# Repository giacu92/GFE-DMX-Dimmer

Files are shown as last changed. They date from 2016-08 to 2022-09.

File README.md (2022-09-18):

# DMX-Dimmer
DIY 5 channels dmx dimmer for 4 stage halogen lights.

Get the full assembled board: [http://gfehandmade.bigcartel.com/product/dmx-dimmer-for-4-stage-halogen-lamps](http://giacu92.bigcartel.com/product/dmx-dimmer-for-4-stage-halogen-lamps)

* Author: Giacomo Mammarella
* email: giacu92@gmail.com
* [YouTube video test 1](https://www.youtube.com/watch?v=KfEGCJoeCmY): testing video n1: lamp test
* [YouTube video test 2](https://www.youtube.com/watch?v=TXi1G5LvkLE): testing video n2: strobe and dimming

# About software:
The software is based on a finite state machine. The DMX start address can be choosen on the software  modifying "#define DMX_START_ADDRESS 65".
The DMX channels are currently set like following:
* DMX CHANNEL 65: lamp 1 dimmer (0 -> 100% fade)
* DMX CHANNEL 66: lamp 2 dimmer 
* DMX CHANNEL 67: lamp 3 dimmer 
* DMX CHANNEL 68: lamp 4 dimmer 
* DMX CHANNEL 69: strobo all lamps at chosen speed (40 - 255 strobe from 100ms to 1s)

# _HardwareSerial0.cpp EDIT:_
To let Arduino IDE compile the code we need to do some mods to the _HardwareSerial0.cpp_ file.
On my current Mac OSX Arduino version (1.6.10) the file is placed at the following path:
**Arduino/Contents/Java/hardware/arduino/avr/cores/arduino/HardwareSerial0.cpp**.
Inside it we need to comment out the whole block between line 40 and line 51:
```
/*
#if defined(USART_RX_vect)
  ISR(USART_RX_vect)
#elif defined(USART0_RX_vect)
  ISR(USART0_RX_vect)
#elif defined(USART_RXC_vect)
  ISR(USART_RXC_vect) // ATmega8
#else
  #error "Don't know what the Data Received vector is called for Serial"
#endif
  {
    Serial._rx_complete_irq();
  }
*/
```
That's because we need to tell the Arduino IDE that inside the code we wrote our personal Interrupt Service Routine ("ISR") and we need it to use it in DMX serial communications.
Remember to remove the mods after uploading the code or Serial communications ( like the one we use in Serial.print() ) wont work anymore.

You can find my copy of modded _HardwareSerial0.cpp_ inside the file list.

# File list:
* [DMX_dimmer.brd](https://github.com/giacu92/DMX-Dimmer/blob/master/DMX_dimmer.brd): the Cadsoft Eagle 6.5 board file.
* [DMX_dimmer.sch](https://github.com/giacu92/DMX-Dimmer/blob/master/DMX_dimmer.sch): the Cadsoft Eagle 6.5 schematic file for the board.
* [Code](https://github.com/giacu92/DMX-Dimmer/tree/master/dmx_dimmer): the folder containingh the sketch for the project.
* [HardwareSerial0.cpp](https://github.com/giacu92/DMX-Dimmer/blob/master/HardwareSerial0.cpp): The **MODIFIED** _HardwareSerial0.cpp_ for uploading the code

# Connections:
Board

# Some pics:
Painting the enclosure and test fitting the pcb:


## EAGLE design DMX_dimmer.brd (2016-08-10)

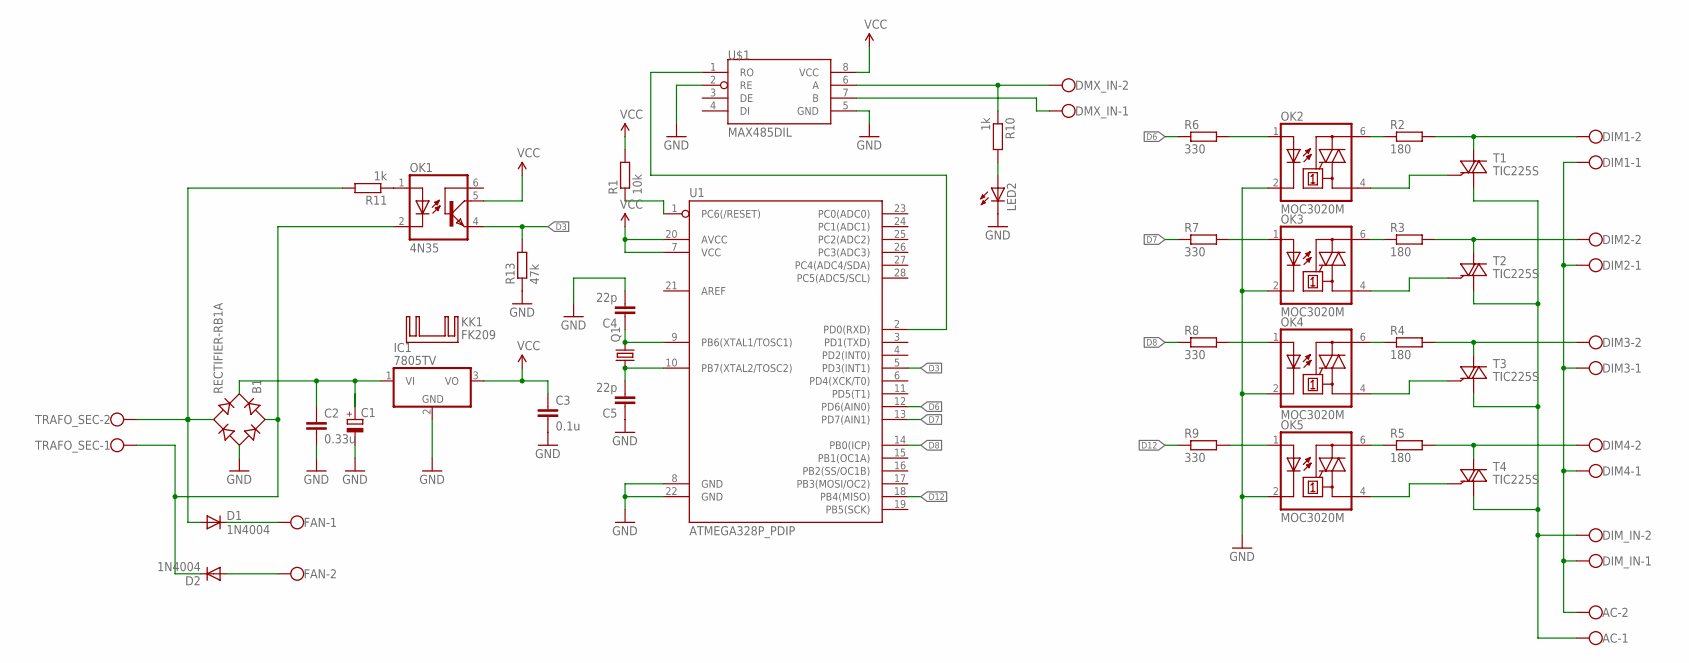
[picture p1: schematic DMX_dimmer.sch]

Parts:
AC: W237-102
B1: RECTIFIER-RB1A; RB1A
C1: CPOL-EUE5-10.5; E5-10,5
C2: 0.33u; C050-024X044
C3: 0.1u; C050-024X044
C4, C5: 22p; C025-024X044
D1, D2: 1N4004; DO41-10
DIM1, DIM2, DIM3, DIM4: W237-102
DIM_IN: W237-102
DMX_IN: W237-102
FAN: W237-102
IC1: 7805TV; TO220V
KK1: FK209
LED2: LED3MM
OK1: 4N35; DIL06
OK2, OK3, OK4, OK5: MOC3020M; DIL06
Q1: CRYSTALHC49U-V; HC49U-V
R1: 10k; 0207/7
R2, R3, R4, R5: 180; 0207/2V
R6, R7, R8, R9: 330; 0207/7
R10, R11: 1k; 0207/7
R13: 47k; 0207/7
T1, T2, T3, T4: TIC225S; TO220DS
TRAFO_SEC: W237-102
U1: ATMEGA328P_PDIP; DIL28-3
U$1: MAX485DIL; DIL08

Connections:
D3: OK1.4 (EMI), R13.2, U1.5 (PD3(INT1))
D6: R6.1, U1.12 (PD6(AIN0))
D7: R7.1, U1.13 (PD7(AIN1))
D8: R8.1, U1.14 (PB0(ICP))
D12: R9.1, U1.18 (PB4(MISO))
DIM_IN-1: AC.2, DIM1.1, DIM2.1, DIM3.1, DIM4.1, DIM_IN.1
DIM_IN-2: AC.1, DIM_IN.2, T1.A1, T2.A1, T3.A1, T4.A1
GND: B1.-, C1.-, C2.2, C3.2, C4.2, C5.1, IC1.2 (GND), LED2.K (C), OK2.2 (C), OK3.2 (C), OK4.2 (C), OK5.2 (C), R13.1, U1.8 (GND), U1.22 (GND), U$1.2 (RE), U$1.5 (GND)
unnamed: DIM1.2, R2.2, T1.A2
unnamed: OK2.6 (A2), R2.1
unnamed: DIM2.2, R3.2, T2.A2
unnamed: OK4.1 (A), R8.2
unnamed: OK3.6 (A2), R3.1
unnamed: OK3.1 (A), R7.2
unnamed: DIM4.2, R5.2, T4.A2
unnamed: OK2.1 (A), R6.2
unnamed: OK4.6 (A2), R4.1
unnamed: OK5.6 (A2), R5.1
unnamed: OK5.4 (A1), T4.G
unnamed: OK4.4 (A1), T3.G
unnamed: OK3.4 (A1), T2.G
unnamed: C5.2, Q1.1, U1.10 (PB7(XTAL2/TOSC2))
unnamed: C4.1, Q1.2, U1.9 (PB6(XTAL1/TOSC1))
unnamed: OK2.4 (A1), T1.G
unnamed: DIM3.2, R4.2, T3.A2
unnamed: D1.C, FAN.1
unnamed: D2.A, FAN.2
unnamed: U1.2 (PD0(RXD)), U$1.1 (RO)
unnamed: OK5.1 (A), R9.2
unnamed: LED2.A, R10.2
unnamed: DMX_IN.2, R10.1, U$1.6 (A)
unnamed: DMX_IN.1, U$1.7 (B)
unnamed: OK1.1 (A), R11.1
unnamed: R1.1, U1.1 (PC6(/RESET))
unnamed: B1.AC1, D2.C, OK1.2 (C), TRAFO_SEC.1
unnamed: B1.+, C1.+, C2.1, IC1.1 (VI)
unnamed: B1.AC2, D1.A, R11.2, TRAFO_SEC.2
VCC: C3.1, IC1.3 (VO), OK1.5 (COL), R1.2, U1.7 (VCC), U1.20 (AVCC), U$1.8 (VCC)

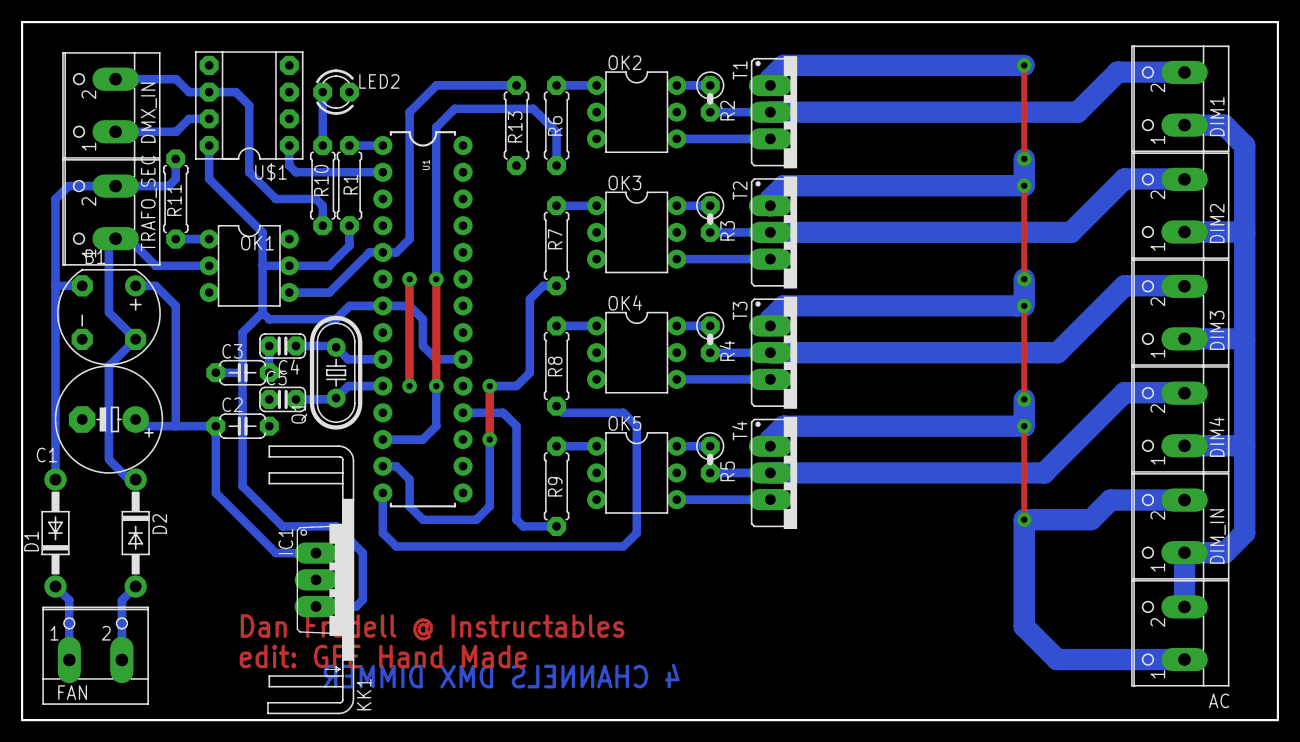
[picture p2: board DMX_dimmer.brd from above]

Board: 2 copper layers, 119.4 x 66.3 mm, 45 parts (0 on the bottom side), 38 nets.

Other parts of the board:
U$2: LOGO-GRANDE

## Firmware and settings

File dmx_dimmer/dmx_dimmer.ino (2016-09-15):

#define DMX_START_ADDRESS 65 //start address for the DMX frame to be interpreted

#define DMX_NUM_CHANNELS 5
#define DMX_NUM_FIXTURES 4

enum
{
  DMX_IDLE,
  DMX_BREAK,
  DMX_START,
  DMX_RUN
};

volatile unsigned char dmx_state;
unsigned int dmx_addr;            //current address of the DMX frame

unsigned long startZeroTime = 0;
unsigned long timeElapsed = 0; //Time until end of cycle
boolean zeroCross[] = {false, false, false, false};
int brightness[DMX_NUM_FIXTURES];
int period = 0;

unsigned char dmx_pin[DMX_NUM_FIXTURES] = {6, 7, 8, 12}; 
unsigned char dmx_data[DMX_NUM_CHANNELS]; //hold the dmx data

volatile unsigned char update; //flag
volatile bool strobe = false;

void setup()
{
  update = 0; //flag idle
  dmx_state = DMX_IDLE; //default DMX state

  delay(500);

  attachInterrupt(digitalPinToInterrupt(3), zeroCrossInterrupt, FALLING);

  for (int i = 0; i < DMX_NUM_FIXTURES; i++)
  {
    pinMode(dmx_pin[i], OUTPUT);
    digitalWrite(dmx_pin[i], LOW);

    //initialize UART: 250kbps, 8bits, no parity, 2 stop bits
    UCSR0C |= (USBS0);
    Serial.begin(250000);
  }
}

void loop()
{
  if(!strobe)
    dimmer();
  else
    strobo();

  
  /*
  for (int i=0; i<DMX_NUM_FIXTURES; i++)
  {
    if (dmx_data[i] > 127)
      digitalWrite(dmx_pin[i], HIGH);
    else
      digitalWrite(dmx_pin[i], LOW);
  }*/
}

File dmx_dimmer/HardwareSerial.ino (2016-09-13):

ISR(USART_RX_vect)
{
  static  uint16_t chan_cnt;
  unsigned char status = UCSR0A;
  unsigned char data = UDR0;

  switch (dmx_state)
  {
    case DMX_IDLE:
      if (status & (1 << FE0)) //if a MAB detected goto DMX_BREAK
      {
        dmx_addr = 0;
        dmx_state = DMX_BREAK;
      }
      break;

    case DMX_BREAK: //if the first bit is 0 (valid frame starts here) goto DMX_START
      if (data == 0)
      {
        dmx_state = DMX_START;
      }
      else
      {
        dmx_state = DMX_IDLE;
      }
      break;

    case DMX_START: //ignore the dmx address not equal to device_address
      dmx_addr++;
      if (dmx_addr == DMX_START_ADDRESS) //the next DMX_NUM_CHANNELS bytes we need, store 'em and goto RUN
      {
        chan_cnt = 0;
        dmx_data[chan_cnt++] = data;
        dmx_state = DMX_RUN;
      }
      break;

    case DMX_RUN:
      dmx_data[chan_cnt++] = data;
      //chan_cnt = 0;
      if (chan_cnt >= DMX_NUM_CHANNELS)
      {
        dmx_state = DMX_IDLE;
      }
      break;

    default:
      dmx_state = DMX_IDLE;
      break;
  }
}

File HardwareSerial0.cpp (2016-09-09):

/*
  HardwareSerial0.cpp - Hardware serial library for Wiring
  Copyright (c) 2006 Nicholas Zambetti.  All right reserved.

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
  Modified 23 November 2006 by David A. Mellis
  Modified 28 September 2010 by Mark Sproul
  Modified 14 August 2012 by Alarus
  Modified 3 December 2013 by Matthijs Kooijman
*/

#include "Arduino.h"
#include "HardwareSerial.h"
#include "HardwareSerial_private.h"

// Each HardwareSerial is defined in its own file, sine the linker pulls
// in the entire file when any element inside is used. --gc-sections can
// additionally cause unused symbols to be dropped, but ISRs have the
// "used" attribute so are never dropped and they keep the
// HardwareSerial instance in as well. Putting each instance in its own
// file prevents the linker from pulling in any unused instances in the
// first place.

#if defined(HAVE_HWSERIAL0)

/*
#if defined(USART_RX_vect)
  ISR(USART_RX_vect)
#elif defined(USART0_RX_vect)
  ISR(USART0_RX_vect)
#elif defined(USART_RXC_vect)
  ISR(USART_RXC_vect) // ATmega8
#else
  #error "Don't know what the Data Received vector is called for Serial"
#endif
  {
    Serial._rx_complete_irq();
  }
*/
#if defined(UART0_UDRE_vect)
ISR(UART0_UDRE_vect)
#elif defined(UART_UDRE_vect)
ISR(UART_UDRE_vect)
#elif defined(USART0_UDRE_vect)
ISR(USART0_UDRE_vect)
#elif defined(USART_UDRE_vect)
ISR(USART_UDRE_vect)
#else
  #error "Don't know what the Data Register Empty vector is called for Serial"
#endif
{
  Serial._tx_udr_empty_irq();
}

#if defined(UBRRH) && defined(UBRRL)
  HardwareSerial Serial(&UBRRH, &UBRRL, &UCSRA, &UCSRB, &UCSRC, &UDR);
#else
  HardwareSerial Serial(&UBRR0H, &UBRR0L, &UCSR0A, &UCSR0B, &UCSR0C, &UDR0);
#endif

// Function that can be weakly referenced by serialEventRun to prevent
// pulling in this file if it's not otherwise used.
bool Serial0_available() {
  return Serial.available();
}

#endif // HAVE_HWSERIAL0

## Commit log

2016-08-10 Initial commit
    Cadsoft Eagle board, schematic and Arduino code
    [DMX_dimmer.brd, DMX_dimmer.sch]
2016-09-09 Arduino code
    small bug fixes
    [dmx_dimmer.ino, strobo.ino, zeroCrossInterupt.ino]
2016-09-09 Arduino Code
2016-09-13 debug
    fade works, strobo don’t

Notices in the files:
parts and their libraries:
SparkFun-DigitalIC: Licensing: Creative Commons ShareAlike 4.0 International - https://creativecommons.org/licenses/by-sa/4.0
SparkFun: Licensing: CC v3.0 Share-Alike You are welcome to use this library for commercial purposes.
